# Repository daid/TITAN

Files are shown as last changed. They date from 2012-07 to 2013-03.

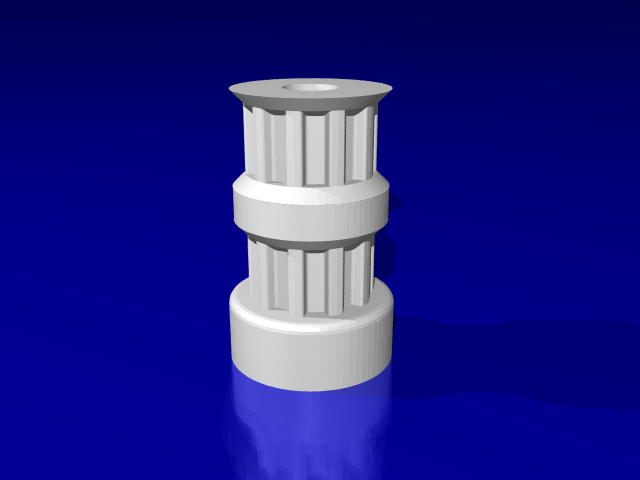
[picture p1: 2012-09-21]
renders/pulleyAxes6mmDualBelt.png

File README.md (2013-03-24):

TITAN
=====

The TITAN is a tiny RepRap based 3D printer. With a 190x190x190 footprint it can print objects up to 80x80x70mm. It is designed for easy transport so sturdy, light and small.

Status
======

The TITAN is under heavy development. The first prototype is still being assembled, and it has not printed yet.

The design files are uploaded, but unfinished at the moment. The following parts are missing:
* Extruder

Parts
=====

I did not make a full Bill Of Materials yet. But my currently used parts are:

* M6 rods. 4x 190mm, 2x 150mm (1 large and 1 small can be cut from 13" rod)
* M8 rods. 2x 100mm
* 2x LM8UU bearings
* 1x Ultimaker hotend
* 1x Ultimaker bowden tube
* T5 timing belt. Multiple lengths cut from 2x 10T5/800 (You need a total of 6 belts of 5mm width, so you need to cut the 10T5 belts in half trough the center)
* 4x NEMA14 motor. 1400 g-cm (20 oz-in)
* 8x 626-ZZ bearings

Not yet defined:
* Screws (lots of M3 screws)
* Extruder parts

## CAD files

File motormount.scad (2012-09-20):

module motorMount()
{
	NEMA14();
	linear_extrude(height=5) difference() {
		square([36,36], center=true);
		circle(r=12);
		mirrored([13,13]) circle(r=3.2/2);
	}
	translate([0,23,0]) rotate([90,0,0]) translate([0,-18+5/2]) difference() {
		linear_extrude(height=5, convexity=2) {
			difference() {
				square([36,36+5], center=true);
				mirrored([10,10]) circle(r=3.2/2);
			}
		}
		mirrored([10,10]) translate([0,0,2]) cylinder(r=3.2,h=5);
	}
	
	/*
	translate([0,-18,0]) rotate([90,0,0]) linear_extrude(height=5) {
		translate([0,-18+5/2]) square([36,36+5], center=true);
	}
	translate([-18,-18,0]) rotate([0,90,0]) linear_extrude(height=5) difference() {
		translate([36/2-5/2,-25/2]) square([36+5,25], center=true);
		translate([36/2-5/2,-25/2-5/2]) mirrored([12,5]) circle(r=3.2/2);
	}

	linear_extrude(height=5) hull() {
		translate([0,-36/2-5/2]) square([36,5], center=true);
		translate([-36/2+5/2,-36/2-25/2]) square([5,25], center=true);
	}

	translate([0,0,-36]) linear_extrude(height=5) hull() {
		translate([0,-36/2-5/2]) square([36,5], center=true);
		translate([-36/2+5/2,-36/2-25/2]) square([5,25], center=true);
	}

	translate([0,0,-36 / 2]) linear_extrude(height=5) hull() {
		translate([0,-36/2-5/2]) square([36,5], center=true);
		translate([-36/2+5/2,-36/2-25/2]) square([5,25], center=true);
	}
	*/
}

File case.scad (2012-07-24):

module bearingHole() {
	circle(r=19/2-laserOffset);
	translate([-14,0]) circle(r=3/2);
	translate([ 14,0]) circle(r=3/2);
}

module caseFrontBack() {
	difference() {
		roundedSquare([180+laserOffset*2,180+4*2+laserOffset*2],r=4);
		translate([ 50, (180/2-caseThickness/2)]) woodConnector3();
		translate([-65, (180/2-caseThickness/2)]) woodConnector3();
		translate([ 50,-(180/2-caseThickness/2)]) woodConnector3();
		translate([-65,-(180/2-caseThickness/2)]) woodConnector3();
		translate([-70, 70]) bearingHole();
		translate([-70,-70]) bearingHole();
		translate([ 85, 55]) rotate(90) woodConnector3();
		translate([ 85,-55]) rotate(90) woodConnector3();
	}
}
module caseFront()
{
	difference() {
		caseFrontBack();
		//The titan text should actually be engraved, but is shown as removed in OpenSCAD. It's easier to change this to engrave in post-processing after you exported to DXF.
		roundedSquare([100,100],r=4);
		translate([ 70,  0]) rotate(90) TITAN();
	}
}
module caseBack()
{
	difference() {
		caseFrontBack();
		translate([-19.5,0]) mirrored([0,65]) rotate(90) woodConnector3();
		/*
		//This is a happy face, you could cut this out of the back.
		translate([-25, 30]) roundedSquare([50,20],r=4);
		translate([-25,-30]) roundedSquare([50,20],r=4);
		difference()
		{
			circle(r=50);
			translate([-20,0]) circle(r=50);
		}
		*/
	}
}
module caseSide() {
	difference() {
		union() {
			square([180+laserOffset*2,180-caseThickness*2+laserOffset*2],center=true);
			translate([ 50, (180/2-caseThickness/2)]) woodConnector1();
			translate([-65, (180/2-caseThickness/2)]) woodConnector1();
			translate([ 50,-(180/2-caseThickness/2)]) woodConnector1();
			translate([-65,-(180/2-caseThickness/2)]) woodConnector1();
		}
		translate([-50, 0]) mirrored([0, 70]) bearingHole();
		translate([ 50, (180/2-caseThickness/2)]) woodConnector2();
		translate([-65, (180/2-caseThickness/2)]) woodConnector2();
		translate([ 50,-(180/2-caseThickness/2)]) woodConnector2();
		translate([-65,-(180/2-caseThickness/2)]) woodConnector2();
		translate([-3,0]) roundedSquare([115,113],r=4);
	
		translate([ 85, 55]) rotate(90) woodConnector3();
		translate([ 85,-55]) rotate(90) woodConnector3();

		translate([-19.5,-72]) rotate(90) woodConnector3(8);
	}
}

module caseBottom() {
	difference() {
		union() {
			square([180-caseThickness*2+laserOffset*2,180-caseThickness*2+laserOffset*2],center=true);
			mirrored([ 55, (180/2-caseThickness/2)]) woodConnector1();
			rotate(90) mirrored([ 55, (180/2-caseThickness/2)]) woodConnector1();
		}
		mirrored([ 55, (180/2-caseThickness/2)]) woodConnector2();
		rotate(90) mirrored([ 55, (180/2-caseThickness/2)]) woodConnector2();
		translate([headPosMin+hotendDistance+(headPosMax-headPosMin)/2, headPosMin+hotendDistance+(headPosMax-headPosMin)/2])
		{
			mirrored([45,45]) circle(r=5);
			translate([0,-43]) mirrored([59.5,0]) circle(r=8/2+laserOffset);
		}
	}
}

module bearingPlate() {
	difference() {
		hull() {
			circle(r=22/2);
			translate([-14,0]) circle(r=10/2);
			translate([ 14,0]) circle(r=10/2);
		}
		translate([-14,0]) circle(r=3/2);
		translate([ 14,0]) circle(r=3/2);
	}
}

module case() {
//	translate([0, (90-caseThickness/2),-50]) rotate([0,90,90]) wood(h=caseThickness) caseFront();
%	translate([0,-(90-caseThickness/2),-50]) rotate([0,90,90]) wood(h=caseThickness) caseBack();
	translate([ (90-caseThickness/2),0,-50]) rotate([0,90,0]) wood(h=caseThickness) caseSide();
	translate([-(90-caseThickness/2),0,-50]) rotate([0,90,0]) wood(h=caseThickness) caseSide();
	translate([0,0,-50-85]) wood(h=caseThickness) caseBottom();
	
	translate([ (90+caseThickness/2), 70,0]) rotate([0,90,0]) wood(h=caseThickness) bearingPlate();
	translate([ (90+caseThickness/2),-70,0]) rotate([0,90,0]) wood(h=caseThickness) bearingPlate();
	translate([-(90+caseThickness/2), 70,0]) rotate([0,90,0]) wood(h=caseThickness) bearingPlate();
	translate([-(90+caseThickness/2),-70,0]) rotate([0,90,0]) wood(h=caseThickness) bearingPlate();
	
	translate([ 70, (90+caseThickness/2),20]) rotate([0,90,90]) wood(h=caseThickness) bearingPlate();
	translate([-70, (90+caseThickness/2),20]) rotate([0,90,90]) wood(h=caseThickness) bearingPlate();
	translate([ 70,-(90+caseThickness/2),20]) rotate([0,90,90]) wood(h=caseThickness) bearingPlate();
	translate([-70,-(90+caseThickness/2),20]) rotate([0,90,90]) wood(h=caseThickness) bearingPlate();
}

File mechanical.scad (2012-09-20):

/*****************************************************/
/* Support modules for none-printed mechanical parts */
/*****************************************************/

/************/
/* Steppers */
/************/

module NEMA8() {
	stepper(size=20.2,length=30,shaftDiameter=4,shaftLength=15,faceplateDiameter=15,screwDistance=16,screwDiameter=2);
}
module NEMA11() {
	stepper(size=28.2,length=45,shaftDiameter=5,shaftLength=20,faceplateDiameter=22,screwDistance=23,screwDiameter=2.5);
}
module NEMA14(l=36) {
	stepper(size=35.2,length=l,shaftDiameter=5,shaftLength=21,faceplateDiameter=22,screwDistance=26,screwDiameter=3);
}
module NEMA17(l=48) {
	stepper(size=42.3,length=l,shaftDiameter=5,shaftLength=24,faceplateDiameter=22,screwDistance=31,screwDiameter=3);
}
module stepper(size=20,length=30,shaftDiameter=4,shaftLength=15,faceplateDiameter=15,screwDistance=16,screwDiameter=2) {
	//Standard model for NEMA steppers. (Note: Up from NEMA23 the design changes at the screw locations, so only use this up to NEMA17)
	%render() union() {
		difference() {
			translate([0,0,-length]) linear_extrude(height=length) minkowski() {
				square([size*0.8,size*0.8], center=true);
				circle(r=size*0.1);
			}
			translate([-screwDistance/2,-screwDistance/2,-3.5]) cylinder(r=screwDiameter/2,h=4);
			translate([ screwDistance/2,-screwDistance/2,-3.5]) cylinder(r=screwDiameter/2,h=4);
			translate([-screwDistance/2, screwDistance/2,-3.5]) cylinder(r=screwDiameter/2,h=4);
			translate([ screwDistance/2, screwDistance/2,-3.5]) cylinder(r=screwDiameter/2,h=4);
		}
		translate([0,0,-1]) cylinder(r=shaftDiameter/2,h=shaftLength+1);
		translate([0,0,-1]) cylinder(r=faceplateDiameter/2,h=2.5);
	}
}

/**********************/
/* Hotend (Ultimaker) */
/**********************/

//ptfeCoupling found in the V2 version of the Ultimaker hotend
module ptfeCoupling() {
	color([0.9,0.9,0.9,0.9]) translate([0,0,1.25]) difference() {
		union() {
			cylinder(r=6/2,h=5);
			translate([0,0,-1.25]) cylinder(r=11.5/2,h=1.25);
			translate([0,0,-10]) cylinder(r=10/2,h=10);
		}
		translate([0,0,-11]) cylinder(r=3.15/2,h=20);
		translate([0,0,-11]) cylinder(r=6.5/2,h=6+1);
	}
}

//Brass connecting tube found in the V1 version of the Ultimaker hotend
module brassTubeV1() {
	color([1,0.9,0,0.9]) difference() {
		translate([0,0,-11]) cylinder(r=4.8/2,h=30);//This length is guessed.
		translate([0,0,-12]) cylinder(r=3.2/2,h=31);
	}
	translate([0,0,-11]) %cylinder(r=6/2,h=30);//#M6 thread#
}

//Brass connecting tube found in the V2 version of the Ultimaker hotend
module brassTubeV2() {
	color([1,0.9,0,0.9]) difference() {
		union() {
			cylinder(r=10/2,h=1);
			translate([0,0,-11]) cylinder(r=4.8/2,h=11);
			translate([0,0,-11]) %cylinder(r=6/2,h=11);//#M6 thread#
			translate([0,0,1]) cylinder(r=4.8/2,h=8);
			translate([0,0,3.7]) %cylinder(r=6/2,h=3.6);//#M6 thread#
		}
		translate([0,0,-12]) cylinder(r=3.2/2,h=25);
	}
}

//The ultimaker peek insulator (see: http://wiki.ultimaker.com/PEEK_insulator)
module peekInsulator() {
	color([1,0.8,0.3,0.9]) render() difference() {
		union() {
			cylinder(r=16.5/2,h=4.2);
			intersection() {
				cylinder(r=14.0/2,h=13+4.2);
				translate([-12.5/2,-15,0]) cube([12.5,30,20]);
			}
		}
		translate([0,0,-1]) cylinder(r=12/2,h=2);
		cylinder(r=6.4/2,h=5);
		cylinder(r=6/2,h=20);	//#M6 thread#
	}
}

//Ultimaker heater block
module heaterBlock() {
	color([0.7,0.7,0.7,0.9]) difference() {
		translate([-5,-25.1/2,0]) cube([16,25.1,12.1]);
		translate([0,0,-1]) cylinder(r=6/2,h=14);	//#M6 thread#
		translate([7,0,8.3]) rotate([90,0,0]) cylinder(r=6/2,h=30,center=true);
		translate([5,0,2]) rotate([90,0,0]) cylinder(r=3/2,h=30,center=true);
		translate([8.5,25.1/2+1,3]) rotate([90,0,0]) cylinder(r=3/2,h=13+1); //#M3 thread#
	}
}

//Ultimaker nozzle, found in the V1 hotend
module nozzleV1() {
	color([1,0.9,0,0.9]) difference() {
		union() {
			cylinder(r=11.5/2,h=4,$fn=6);
			translate([0,0,-6]) cylinder(r=4.8/2,h=6);
			%translate([0,0,-6+1.1]) cylinder(r=6/2,h=4);//#M6 thread#
			translate([0,0,4]) intersection()
			{
				cylinder(r=11.5/2,h=8.7,$fn=6);
				cylinder(r1=11.5/2,r2=0.4,h=8.7);
			}
		}
		translate([0,0,-6-1]) cylinder(r=3.2/2,h=11.5+1);
		cylinder(r=0.4/2,h=20);
	}
}

//Ultimaker nozzle, found in the V2 hotend
module nozzleV2() {
	color([1,0.9,0,0.9]) difference() {
		union() {
			cylinder(r=11.5/2,h=4,$fn=6);
			translate([0,0,-6]) cylinder(r=4.8/2,h=6);
			%translate([0,0,-6+1.1]) cylinder(r=6/2,h=4);//#M6 thread#
			translate([0,0,4]) intersection()
			{
				cylinder(r=11.5/2,h=5,$fn=6);
				cylinder(r1=11.5/2,r2=0.4,h=5);
			}
		}
		translate([0,0,-6-1]) cylinder(r=3.2/2,h=11.5+1);
		cylinder(r=0.4/2,h=11.5);
	}
}

module hotEndV1() {
	rotate([180,0,0]) {
		translate([0,0,13+4.2]) brassTubeV1();
		peekInsulator();
		translate([0,0,13+4.2]) heaterBlock();
		translate([0,0,13+4.2+12.1]) nozzleV1();
	}
}
module hotEndV2() {
	rotate([180,0,0]) {
		ptfeCoupling();
		translate([0,0,0.25+13+4.2]) brassTubeV2();
		translate([0,0,0.25+13+4.2+3.7+12.1]) nozzleV2();
		translate([0,0,0.25+13+4.2+3.7]) heaterBlock();
		translate([0,0,0.25]) peekInsulator();
	}
}

/************/
/* Fan */
/************/
module fan40mm() {
	color([0.5,0.5,0.5,0.9]) linear_extrude(height=10) {
		difference() {
			roundedSquare([40,40], r=4);
			translate([ 32/2, 32/2]) circle(r=4/2);
			translate([ 32/2,-32/2]) circle(r=4/2);
			translate([-32/2, 32/2]) circle(r=4/2);
			translate([-32/2,-32/2]) circle(r=4/2);
			
			intersection() {
				circle(r=40/2);
				square([38,38],center=true);
			}
		}
	}
}

module bearing626()
{
	render() difference()
	{
		cylinder(r=19/2,h=6);
		translate([0,0,-1]) cylinder(r=6/2,h=8);
	}
}

module bearingLM8UU()
{
	% linear_extrude(height=25,center=true) difference() {
		circle(r=16/2);
		circle(r=8/2);
	}
}

module nutM6()
{
	%linear_extrude(height=6) difference()
	{
		circle(r=11.5/2, $fn=6);
		circle(r=5/2);
	}
}

/**************************************************************/
/* Limits, to show max size of the machine during development */
/**************************************************************/
module limits(s = 180, s2=180) {
	translate([-s/2,-s/2,-s/2]) 
	{
		%cube([s,1,1]);
		%cube([1,s,1]);
		%translate([0,s-1,0]) cube([s,1,1]);
		%translate([s-1,0,0]) cube([1,s,1]);

		%translate([0,0,s2-1]) cube([s,1,1]);
		%translate([0,0,s2-1]) cube([1,s,1]);
		%translate([0,s-1,s2-1]) cube([s,1,1]);
		%translate([s-1,0,s2-1]) cube([1,s,1]);

		%cube([1,1,s2]);
		%translate([s-1,0,0]) cube([1,1,s2]);
		%translate([0,s-1,0]) cube([1,1,s2]);
		%translate([s-1,s-1,0]) cube([1,1,s2]);
	}
	//% translate([s/2,-s/2,-s/2]) cube([230,230,320]);//Tantillus
	//% translate([s/2,-s/2,-s/2]) cube([340,355,390]);//Ultimaker
	//% translate([s/2,-s/2,-s/2]) cube([420,410,350]);//Prusa Mendel
	//% translate([s/2,-s/2,-s/2]) cube([11*25.4,11*25.4,11*25.4]);//Printrbot? (need to figure out the outside dimensions)
}

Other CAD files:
scad/motormount.scad
pulley.scad
scad/case.scad
scad/extrusionHead.scad
scad/main.scad
scad/mechanical.scad
scad/pulley.scad
scad/util.scad
scad/xystage.scad
scad/zstage.scad
util.scad
xystage.scad
zstage.scad

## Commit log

2012-07-24 Added prototype TITAN
    [case.scad, extrusionHead.scad, main.scad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]
2012-07-25 Minor updates
    [main.scad, util.scad]
2012-07-30 Fixed the Z stage, the linear bearings where wrong (1mm too small)
    [mechanical.scad, xystage.scad, zstage.scad]
2012-09-20 Update on the TITAN, added X/Y motor mounts and started to work on the Z screw assembly. The motor mounts still need holes in the case for assembly.
    [main.scad, mechanical.scad, motormount.scad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]
2012-09-21 Updated SCAD code to better support pov-ray rendering, added python script for pov-ray rendering.
    [case.scad, extrusionHead.scad, main.scad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]
2012-09-27 update on the stl2pov script to allow rendering multiple STL files as a single render with different colors.
    [main.scad]
2012-10-06 Update to the TITAN design, added more parts to the Z stage. Changed the case a bit, so the Z stage guide holder is stronger, and the front hole is larger. Added belts in the SCAD code.
    [case.scad, pulley.scad, util.scad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]
2012-11-29 Updated case design, updated ZScrew assembly design which works.
    [case.scad, main.scad, mechanical.scad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]
2013-01-11 Add finer gradule for displaying different parts.
    [extrusionHead.scad, mechanical.scad, motormount.scad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]
2013-01-13 Small update on the Z stage so it is easier to install.
    [main.scad, zstage.scad]
2013-01-14 Import STLs from a different location.
    [xystage.scad]
2013-03-24 Not working feeder.
    [case.scad, extrusionHead.scad, main.scad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]
2014-07-07 Added 200mm titan design, unfinished.
